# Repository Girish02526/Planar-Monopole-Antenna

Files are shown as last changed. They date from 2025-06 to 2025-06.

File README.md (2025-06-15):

# Planar Monopole Antenna Project

This repository contains all the resources related to the **Planar Monopole Antenna for Wireless and Energy Harvesting Applications**.

## 📸 Project Images

Below are the sequential images demonstrating various stages and components of the project:

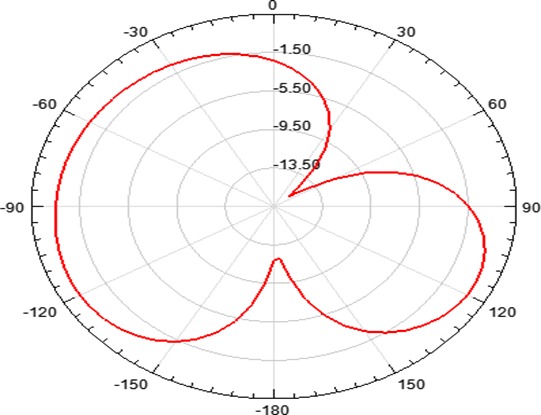
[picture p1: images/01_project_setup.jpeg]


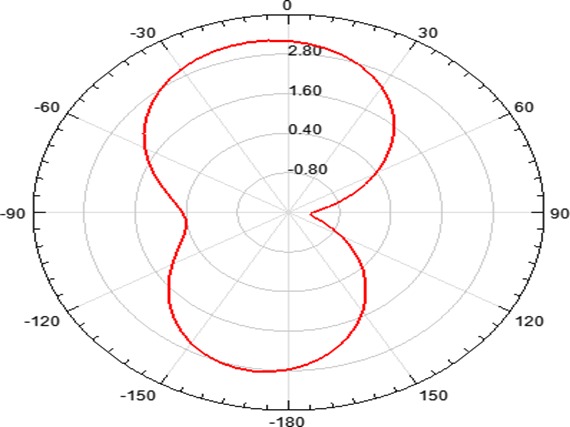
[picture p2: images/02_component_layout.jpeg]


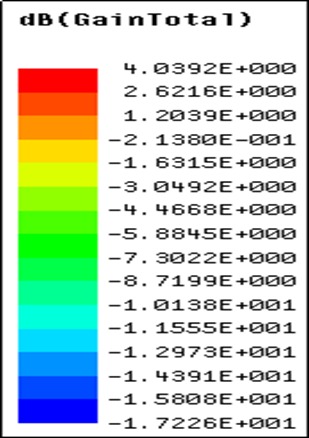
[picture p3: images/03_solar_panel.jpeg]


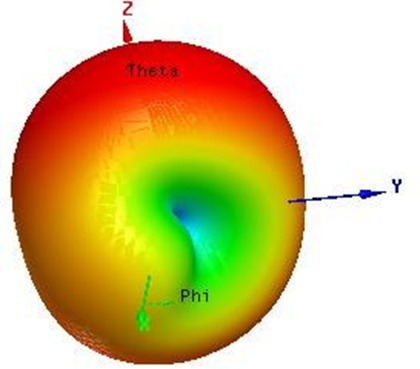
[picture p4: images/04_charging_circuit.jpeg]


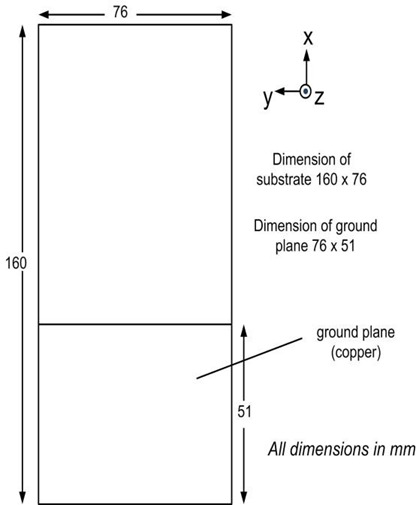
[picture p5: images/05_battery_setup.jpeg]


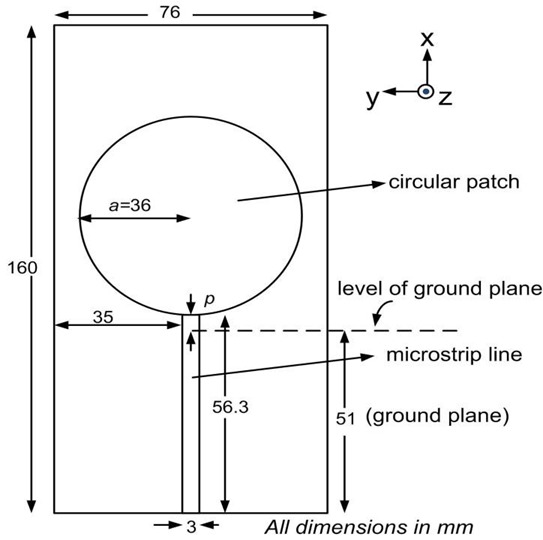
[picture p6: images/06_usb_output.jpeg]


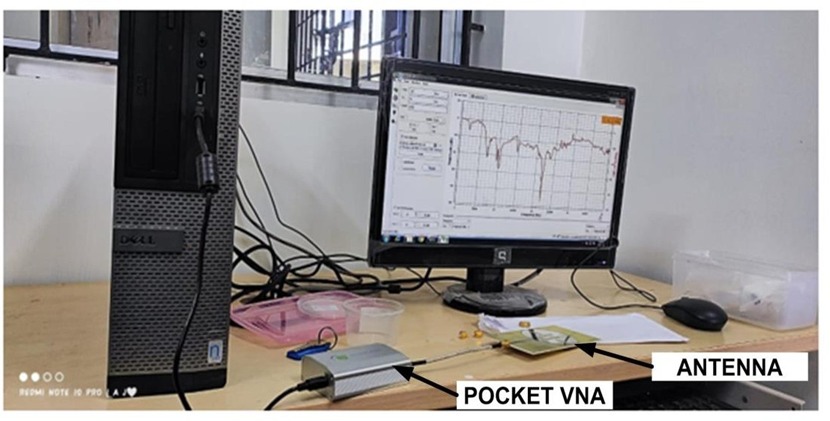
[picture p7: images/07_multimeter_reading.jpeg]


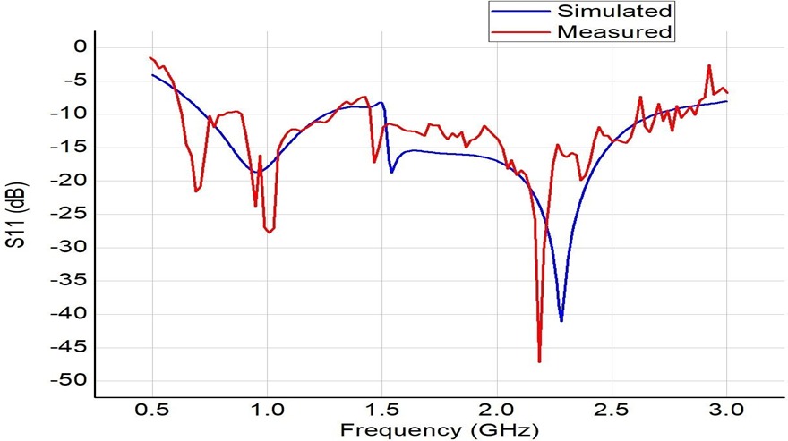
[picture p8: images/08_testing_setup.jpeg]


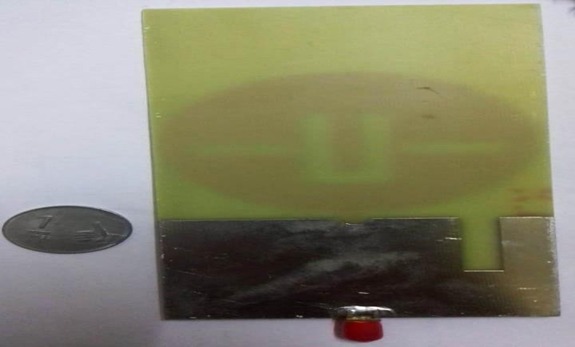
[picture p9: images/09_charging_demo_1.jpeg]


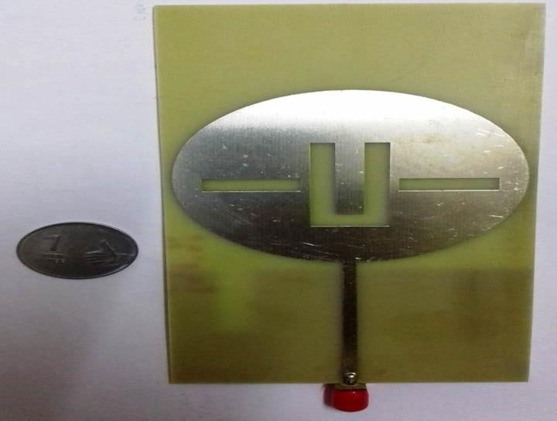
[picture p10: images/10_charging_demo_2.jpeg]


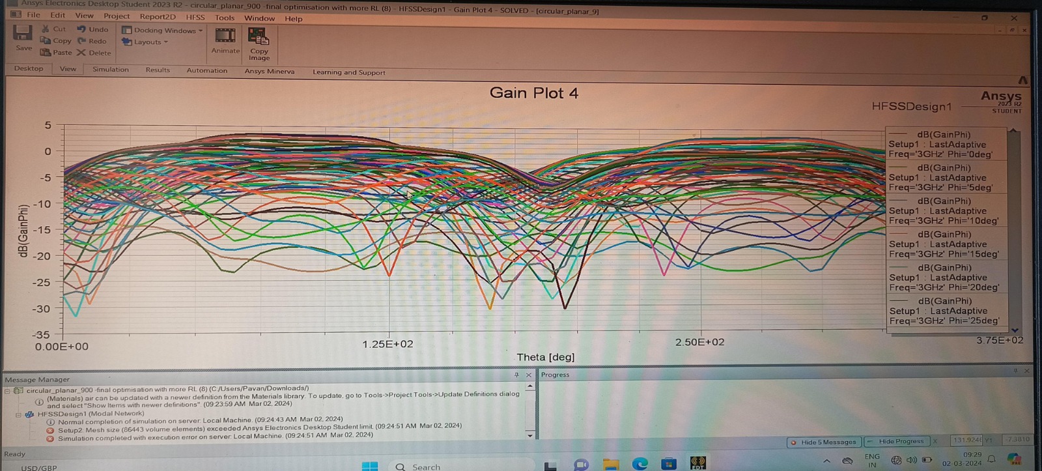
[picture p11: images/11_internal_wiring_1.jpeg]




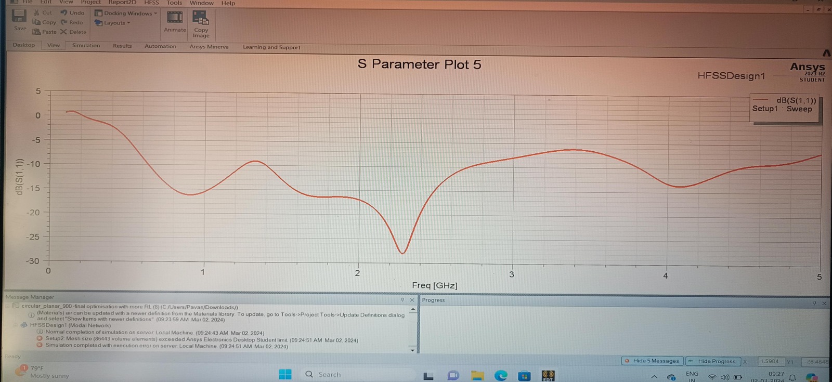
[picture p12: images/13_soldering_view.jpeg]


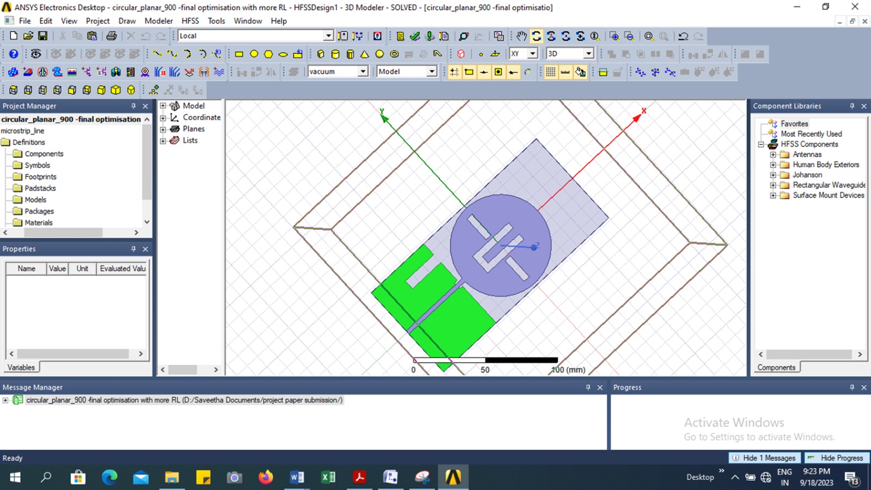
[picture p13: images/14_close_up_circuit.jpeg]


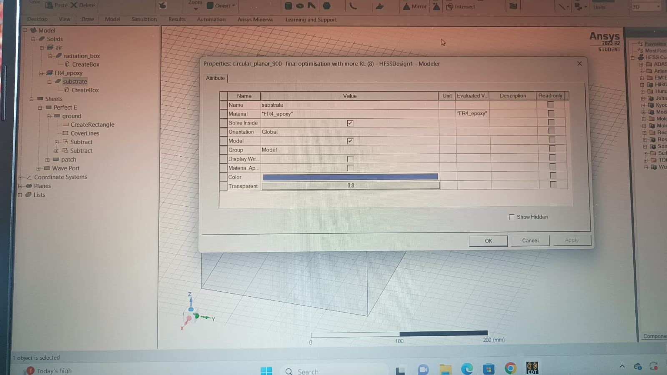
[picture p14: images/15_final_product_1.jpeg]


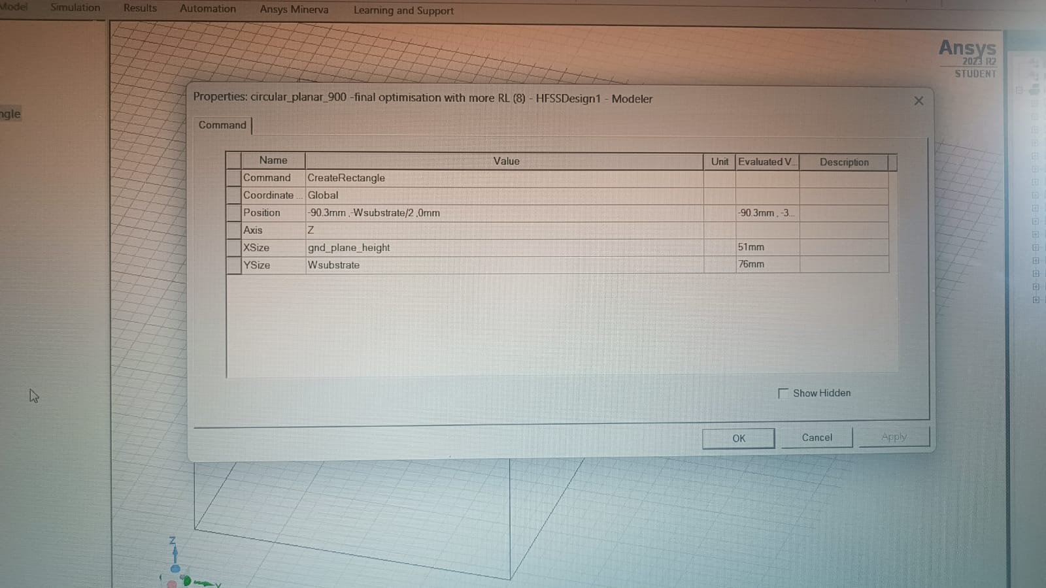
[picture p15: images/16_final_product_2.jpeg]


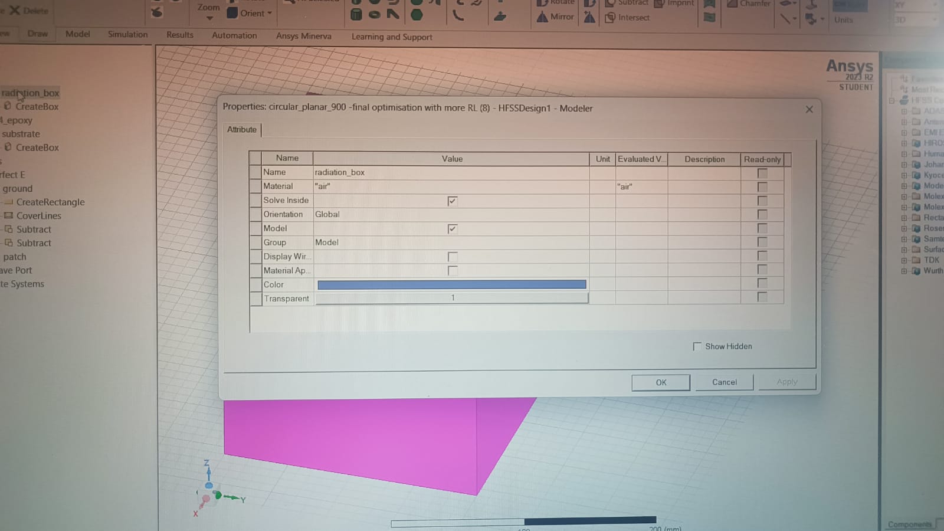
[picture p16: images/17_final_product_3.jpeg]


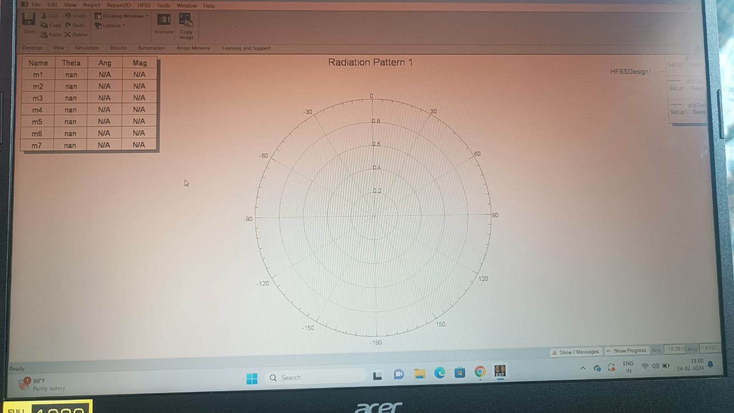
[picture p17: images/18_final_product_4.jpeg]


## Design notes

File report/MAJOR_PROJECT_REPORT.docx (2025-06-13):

## Design Of Planar Monople Antenna For Wireless and Energy Harvesting Applications

## Amit Kumar Varshney,

Dept of Electronics and Communication Engineering,

Saveetha Engineering college (Autonomous)

Chennai , TamilNadu

Chemirthipalli Girish,

Dept of Electronics and Communication Engineering,

Saveetha Engineering college (Autonomous)

Chennai , TamilNadu

girish02526@gmail.com

Duggineni Bhanu Prakash,

Dept of Electronics and Communication Engineering,

Saveetha Engineering college (Autonomous)

Chennai , TamilNadu

bhanuchowdaryduggineni@gmail.com

Abstract— A planar circular monopole antenna with slots in the patch as well as in the ground plane is presented. Slots of different shapes and sizes are etched in patch and ground plane to bring down the resonant frequency of proposed antenna and increase its bandwidth. The antenna operates over a wide frequency range, covering some of wireless standards/protocols at the same time, such as Wi-Fi, WiMAX, Bluetooth, RFID and GPS (L1). The antenna is simulated in HFSS and measured using pocket VNA. The simulated result shows S11 parameter less than -10dB from 0.72GHz to 1.24GHz and again from 1.52GHz to 2.65GHz. The measured result shows S11 parameter of around -10dB and less from 0.628GHz to 1.28GHz and again from 1.466GHz to 2.72GHz. Without using any slot in the ground plane and patch, the simulated result shows S11 parameter less than -10dB from 0.85GHz to 2.18GHz. The simulated gain obtained is around 4dBi at almost all the frequencies. Therefore simulated and measured results are in close agreement. Without using slots in the patch and ground plane, the simulated S-parameter shows S11 less than -10dB from 0.84GHz to 2.25GHz. The overall dimension of the fabricated antenna is 160mm by 76mm. The antenna is fabricated on FR4 epoxy substrate having and loss tangent 0.02. The proposed antenna, besides its use in wireless communication, finds application in energy harvesting where low frequencies are abundantly present in the environment.

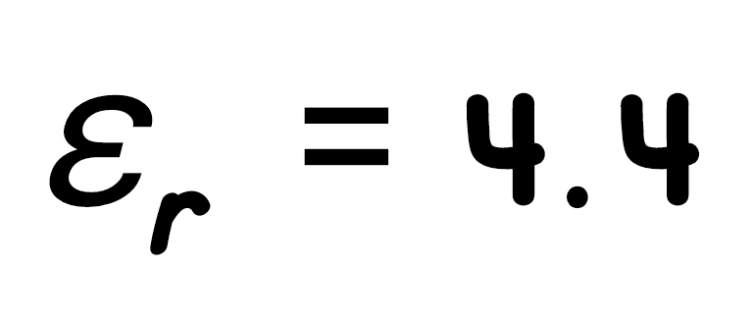
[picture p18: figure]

Keywords—circular monopole, energy harvesting, slots.

# I. Introduction

Owing to the emergence of several wireless standards and protocols it has become necessary to design an antenna that can operate in multiple frequencies. This calls for broadbanding an antenna. A planar monopole antenna is inherently broadband because it is evolved from microstrip patch antenna by increasing the substrate height and decreasing the permittivity of substrate since both height and permittivity of the substrate have direct affect on the bandwidth [1, 2]. For planar monopole antenna ground plane can be thought to be at infinity and permittivity close to 1 (air substrate) [3]. Increasing the thickness of the monopole further increases the bandwidth [3]. At the design frequency, the monopole antennas should be a quarter of a wavelength long. If the radius of the cylinder is made thicker, the bandwidth of the antennas can be increased. The same approach applies to planar monopole antennas: instead of utilizing a 50 ohm metal strip for the monopole, a wider strip (rectangular shape) or any other shape (triangular, circular, ellipse, etc.) can be used to achieve broadband characteristics. Further optimization of the broadband characteristics can be performed by introducing defects in the ground plane (by etching slots or slits) and/or etching slots/slits in the monopole. This is the guiding premise for this type of research. Different authors in the past have reported modification in the basic structure of planar microstrip and monopole antennas in order to improve the bandwidth and also to provide miniaturization. In one such paper [4], the author has reported an array of two U shaped planar monopole antennas and a slit in the ground plane to achieve 80% fractional bandwidth. Authors in [5] have designed annular ring shaped microstrip patch antenna with ground plane of hexagonal shaped to achieve 151% of fractional bandwidth due to the excitation of closely spaced multimodes [5]. The multimodes may be from same antenna or from two closely spaced antennas [6-7]. In [8], authors have reported that cutting U shaped slot in the microstrip patch/ground plane enhances bandwidth due to alteration of current path [8]. In [9] authors have reported two-element multiple-input multiple-output (MIMO) antenna for ultra wideband applications with tapered feed instead of standard feed. In this work, the two antennas are orthogonally fed which resulted in good isolation between antennas. In [10], the authors have reported three radiating strips and a back coupling pad to improve impedance matching. This structure achieves a wide bandwidth of 2.972GHz from 2.315GHz to 5.285GHz. In [11], the authors have reported U shaped microstrip patch with circular slots in the ground plane achieving 81% fractional bandwidth. In [12], the authors have reported an eye shaped slot in dipole antenna. This slot improves the gain and return loss bandwidth of antenna. The frequency of this antenna is from 3.1 to 12 GHz. The authors in [13] have reported etching complementary split ring resonator on the radiating patch of the planar monopole antenna. By this technique, a fractional bandwidth of upto 76% has been achieved.

Antennas also find applications in harnessing RF energy from environment. For better harnessing the RF energy from ambient environment, it is desired to have the antenna radiation pattern almost equal in all the directions. Monopole antennas are a very good choice for such applications. Antennas for energy harvesting applications do not require to be compact. However planar antennas are preferred as these can be integrated with microwave circuitry required with antenna for RF energy harvesting like rectifiers etc. [14] Authors in [14] have designed and optimized a rectifier combined with a broadband planar monopole antenna (called rectina) which can be used for RF energy harvesting.

The advancement of current world technology, as well as customer demand for multiple services offered by a single wireless device, has influenced the need for an antenna capable of transmitting and receiving electromagnetic waves across multiple frequency bands. A distinct frequency band is associated with each wireless service. The most prevalent wireless services are listed, along with their respective frequency ranges.

Frequency ranges wireless service

860-960MHz RFID

2.51-2.55GHz WiMAX band

2100MHz UMTS(3G of GSM)

824-890MHz CDMA

1575+-10MHz GPS

890-915MHz and 935-960MHz GSM(900)

1710-1780MHz and 1810-1880MHz GSM(1800)

1920-1980MHz and 2110-2170MHz 3G

2300-2400MHz 4G

2400-2483MHz Wi-Fi

In this paper the authors have proposed a novel broadband planar monopole antenna that will cover simultaneously a number wireless standards and protocols (especially the standards at low frequencies) so that the proposed antenna can be used in wireless as well as energy harvesting applications.

# II. Design of the proposed monopole antenna

A simple circular monopole antenna is designed and simulated in simulation software as shown in Fig. 1. One side of the substrate consists of circular monopole with microstrip line (top side) and the other side (bottom side) consists of only ground plane. The substrate used is FR4 epoxy having relative permittivity εr=4.4 and thickness h=1.6mm. The dimensions are optimized for better impedance matching. The initial length of monopole is obtained using the available analytical formulation available in literature [3]. The length of the wire monopole antenna is quarter-wave long at the design frequency with some correction factor. With increase in the thickness of the radius of the wire, the bandwidth increases. So for broadband monopole antenna the lower frequency corresponding to VSWR=2 or S11=-10dB can be calculated by equating the area of the radiating structure with the equivalent cylindrical monopole antenna having the same height as that of original antenna. Let us consider the case of a circular monopole antenna of radius ‘a’. The equivalent length of the cylindrical monopole antenna is L=2a. Now area of circle is . Area of cylinder of length L and radius r is . Equating the two areas we obtain .

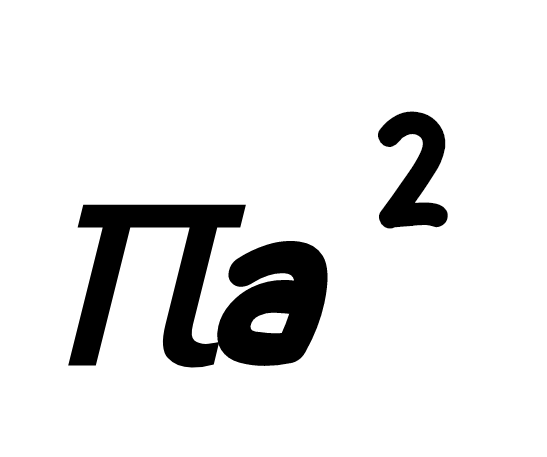
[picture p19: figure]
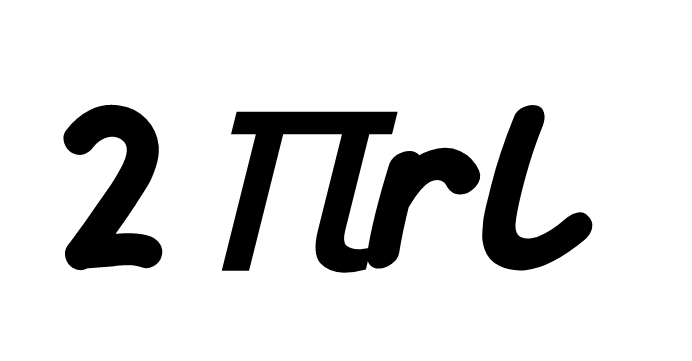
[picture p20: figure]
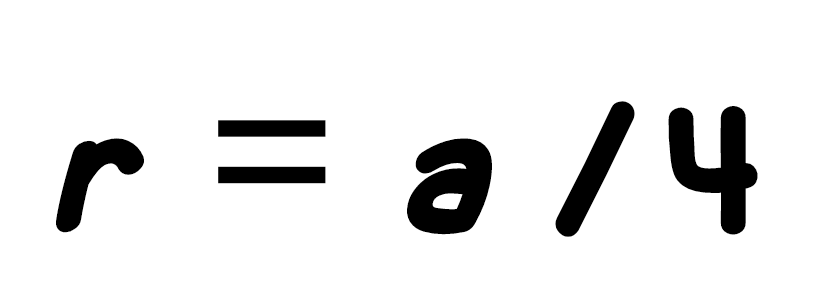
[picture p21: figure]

For a cylindrical wire monopole antenna having length L and radius r, the following relation holds [3]

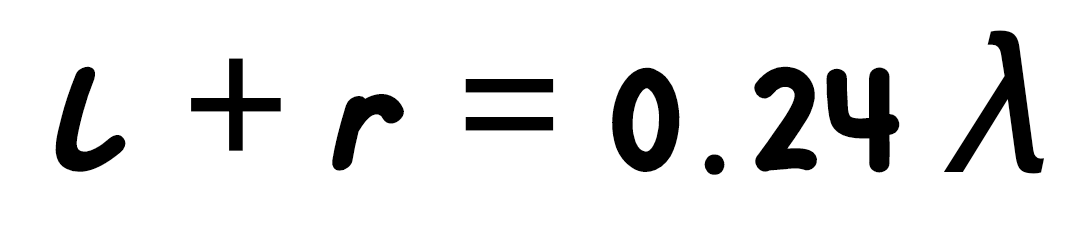
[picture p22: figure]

(1)

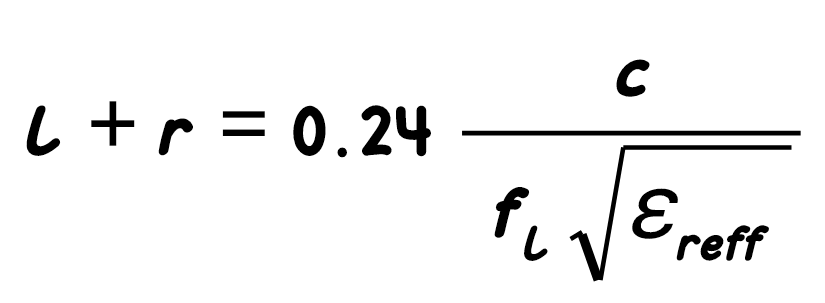
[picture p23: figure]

(2)

where is the lower cutoff frequency

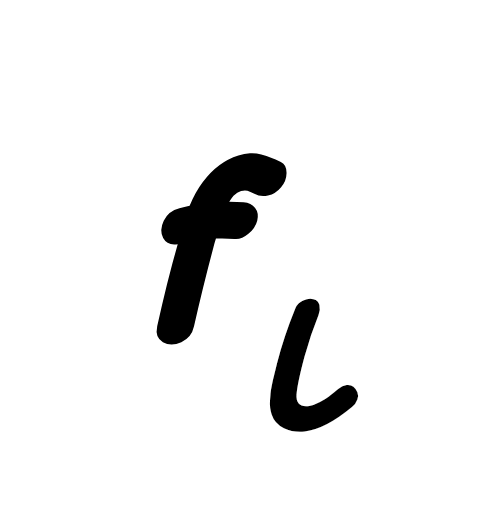
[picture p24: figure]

Here (since we are considering air dielectric)

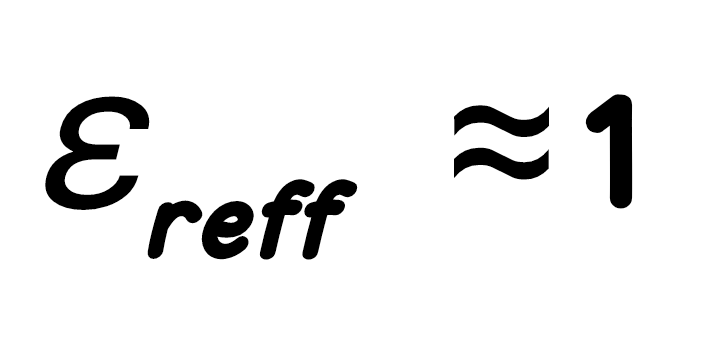
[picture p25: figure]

This simplifies to

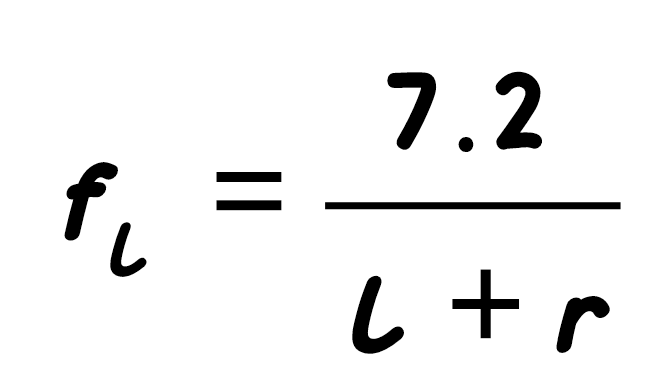
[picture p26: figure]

GHz (3)

where L and r to be considered in cm.

In order to account for the gap ‘p’ (3) modifies to

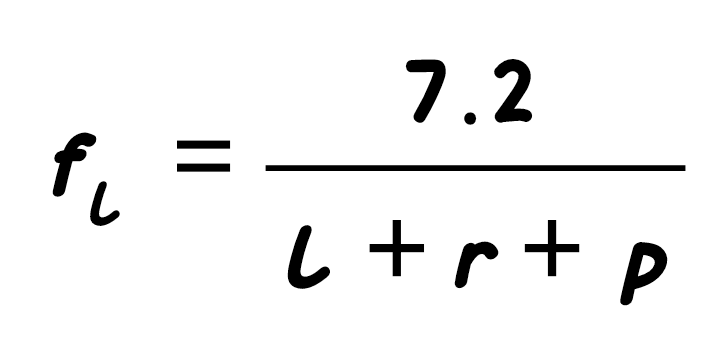
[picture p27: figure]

GHz (4)

This is the basic design equation.

In the present optimized design, a=36mm. Hence r=9mm, L=72mm, p=5.3mm. Putting these values in (4) we obtain fL=834.298MHz.

(a)

(b)

Fig. 1 Top side (a) and bottom side (b) of simple circular monopole antenna on FR4 epoxy substrate having thickness 1.6mm and relative permittivity 4.4

After optimization of the basic circular monopole antenna, three slots in the patch are introduced, one U shaped and two rectangular shaped on either side of U shaped, and two slots in the ground plane, one slot of semicircular shape just below the transmission line and another rectangular slot at a distance away from the transmission line. The dimensions of the slots in the patch and in the ground plane are optimized in the simulation software for better impedance matching. The final optimized dimensions of the antenna with all the slots is shown in Fig. 2

(a)

(b)Fig. 2 Top side (a) and bottom side (b) of slotted circular monopole antenna on FR4 epoxy substrate having thickness 1.6mm and relative permittivity 4.4

# III. Results And Discussion

The simulated S11 parameter (magnitude only) less than -10dB for the simple circular shaped monopole antenna is obtained from 0.85GHz to 2.18GHz as shown in Fig. 3. After cutting slots in the patch and ground plane, the S11 parameter less than -10dB is obtained from 0.72GHz to 1.24GHz and again from 1.52GHz to 2.65GHz as shown in the same Fig. 3 We thus observe that after cutting slots, the lower cutoff frequency is reduced and the upper cutoff frequency is increased, S11 parameter is slightly more than -10dB around 1.3GHz. The simulated 3D radiation pattern (plot of gain in dBi) of the slotted monopole antenna at 0.9GHz is shown in Fig.4. The E-plane and H-plane radiation pattern of the proposed antenna is shown in Fig. 5. The proposed antenna is then fabricated and its S-parameter measured using pocket VNA. The fabricated antenna is shown in Fig. 6 and the pocket VNA with the antenna connected is shown in Fig. 7. The measured S-parameter shows S11 less than -10dB from 0.628GHz to 1.28GHz and again from 1.466GHz to 2.72GHz. The measured and simulated S-parameter S11 are compared in Fig. 8. The results show good agreement between measured and simulated S-parameter S11.

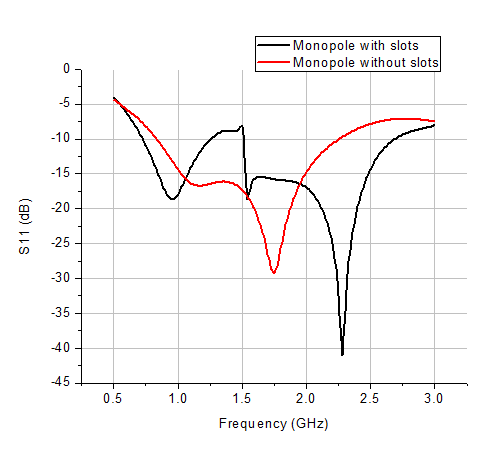
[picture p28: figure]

Fig. 3. Simulated S11 parameter (magnitude only) of simple circular monopole antenna with and without slots.

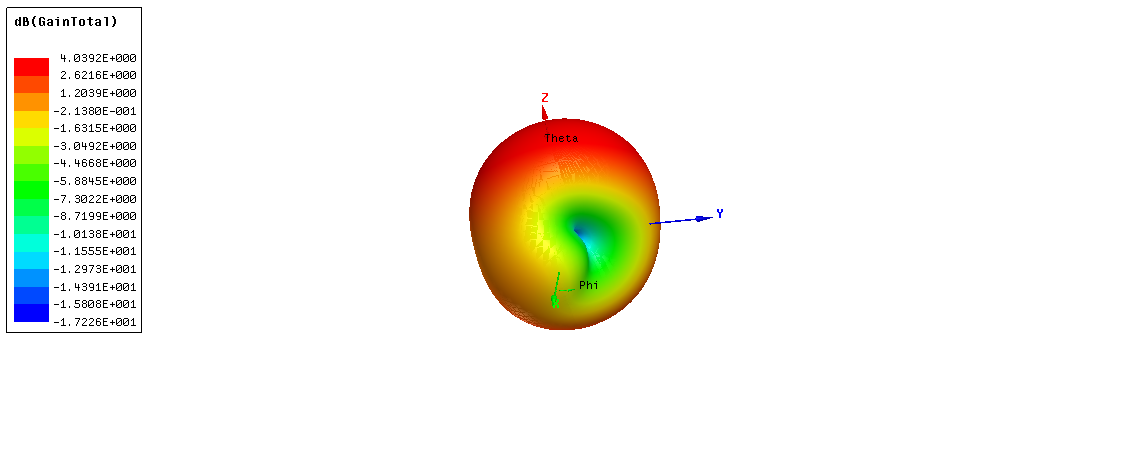
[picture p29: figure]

Fig. 4. Simulated 3D radiation pattern of slotted monopole antenna at 0.9GHz

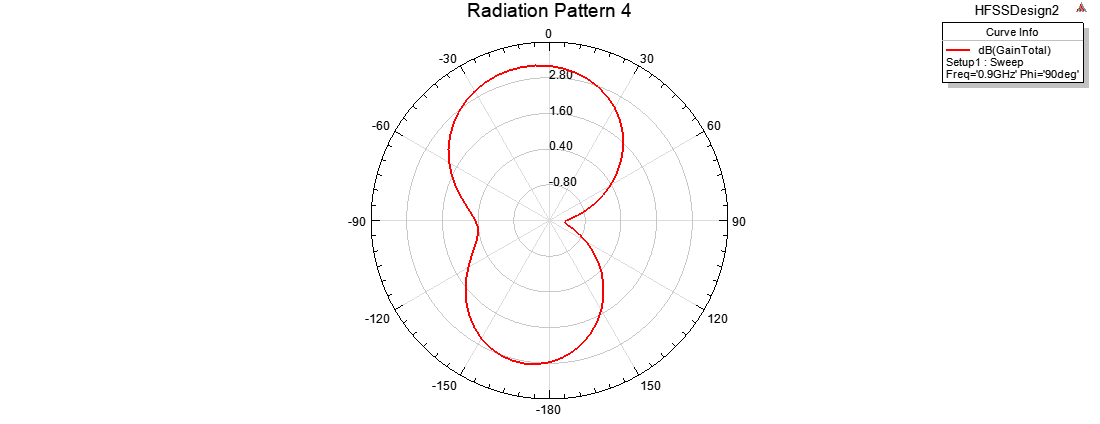
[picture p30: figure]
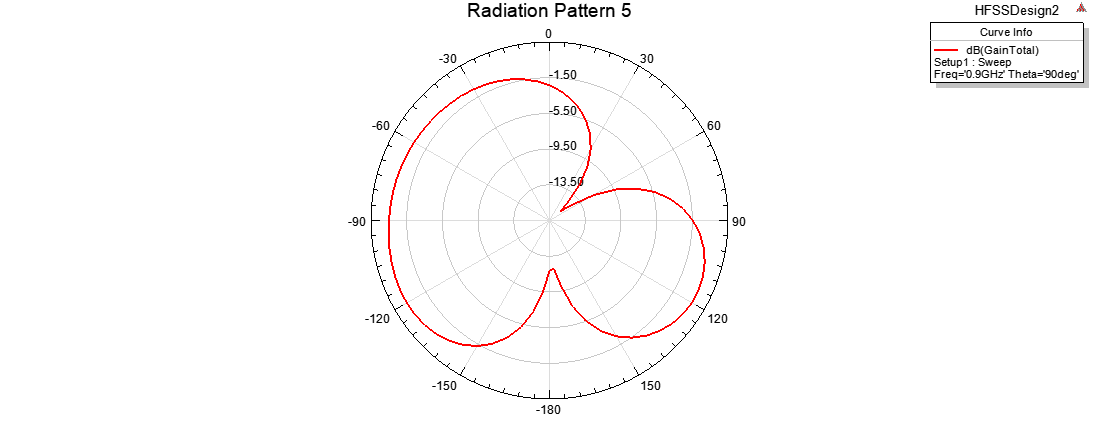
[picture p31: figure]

(a) (b) (b)

Fig. 5. Simulated 2D radiation pattern in y-z plane () (H-plane) (a) and in x-y plane () (b) at 0.9GHz (E-plane)

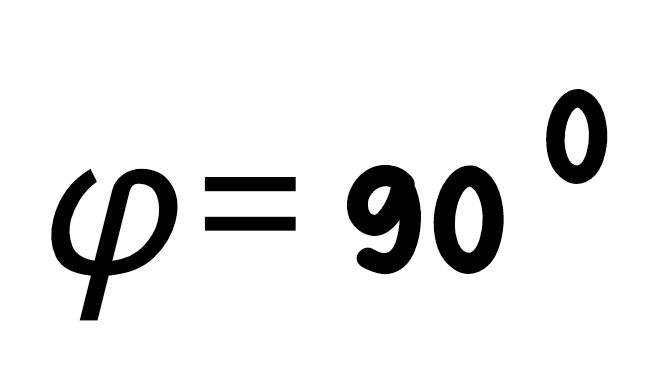
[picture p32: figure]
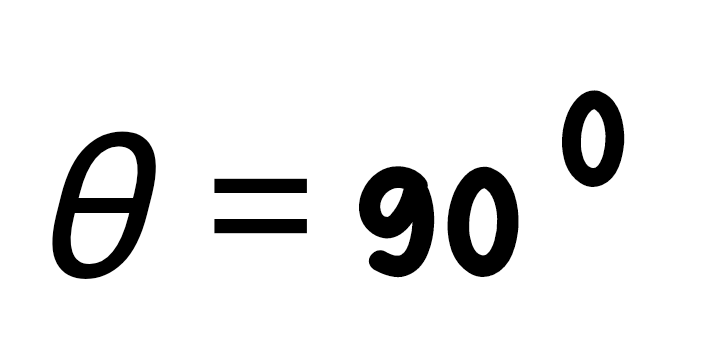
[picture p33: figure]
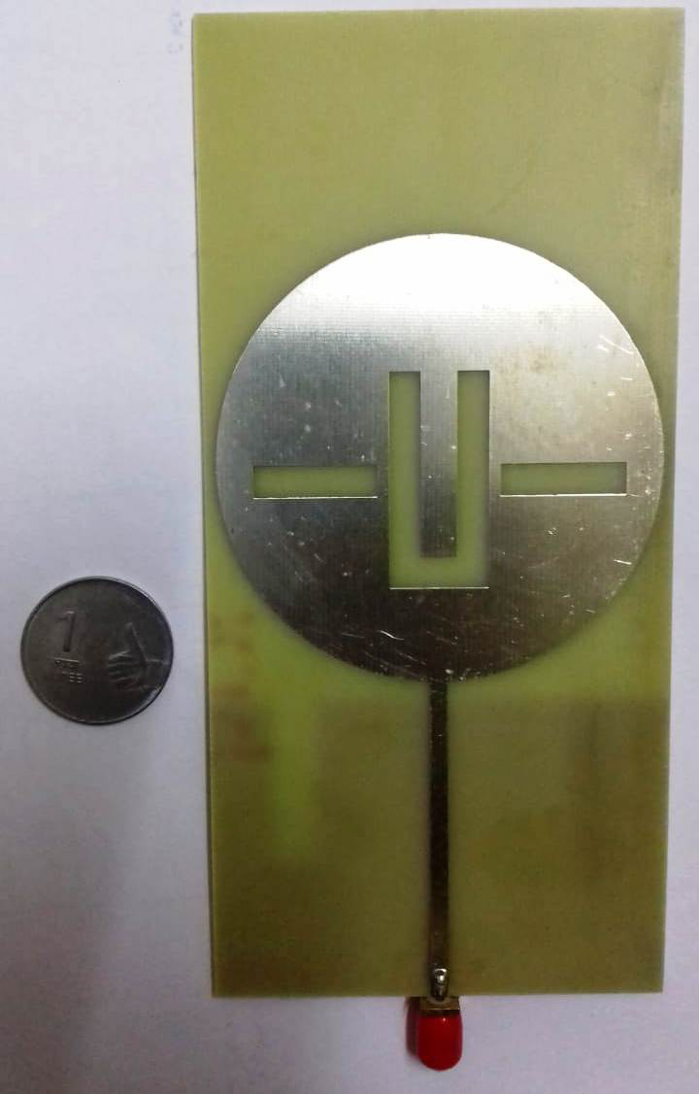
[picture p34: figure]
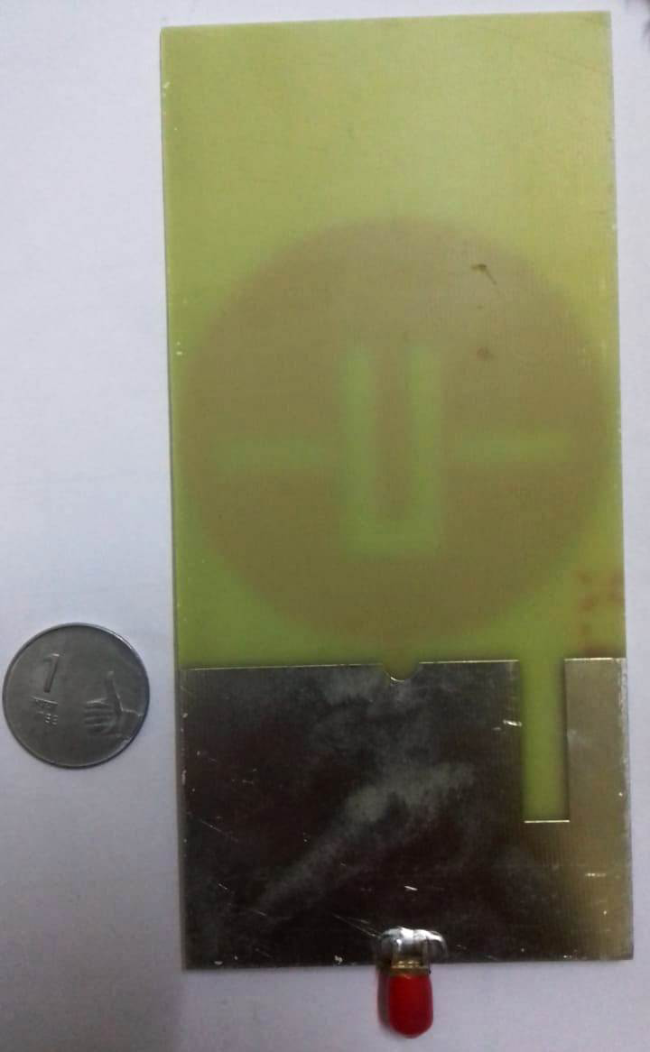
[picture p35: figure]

(a) (b)

Fig. 6. Top side view (a) and bottom side view (b) of fabricated slotted monopole antenna

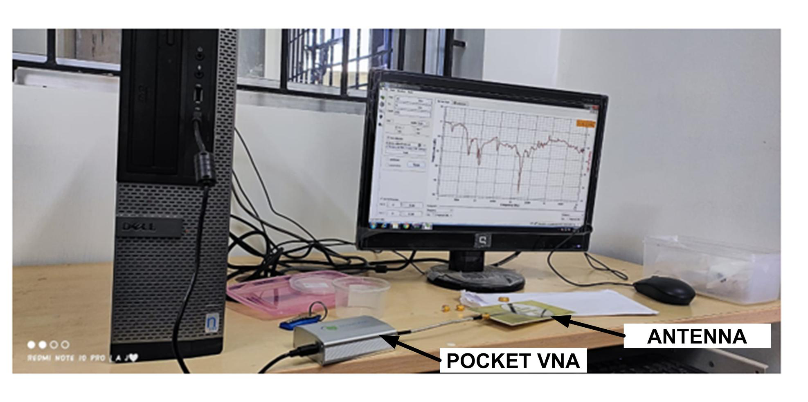
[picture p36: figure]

Fig. 7. Experimental set for the measurement of S11 parameter of the proposed antenna using pocket VNA.

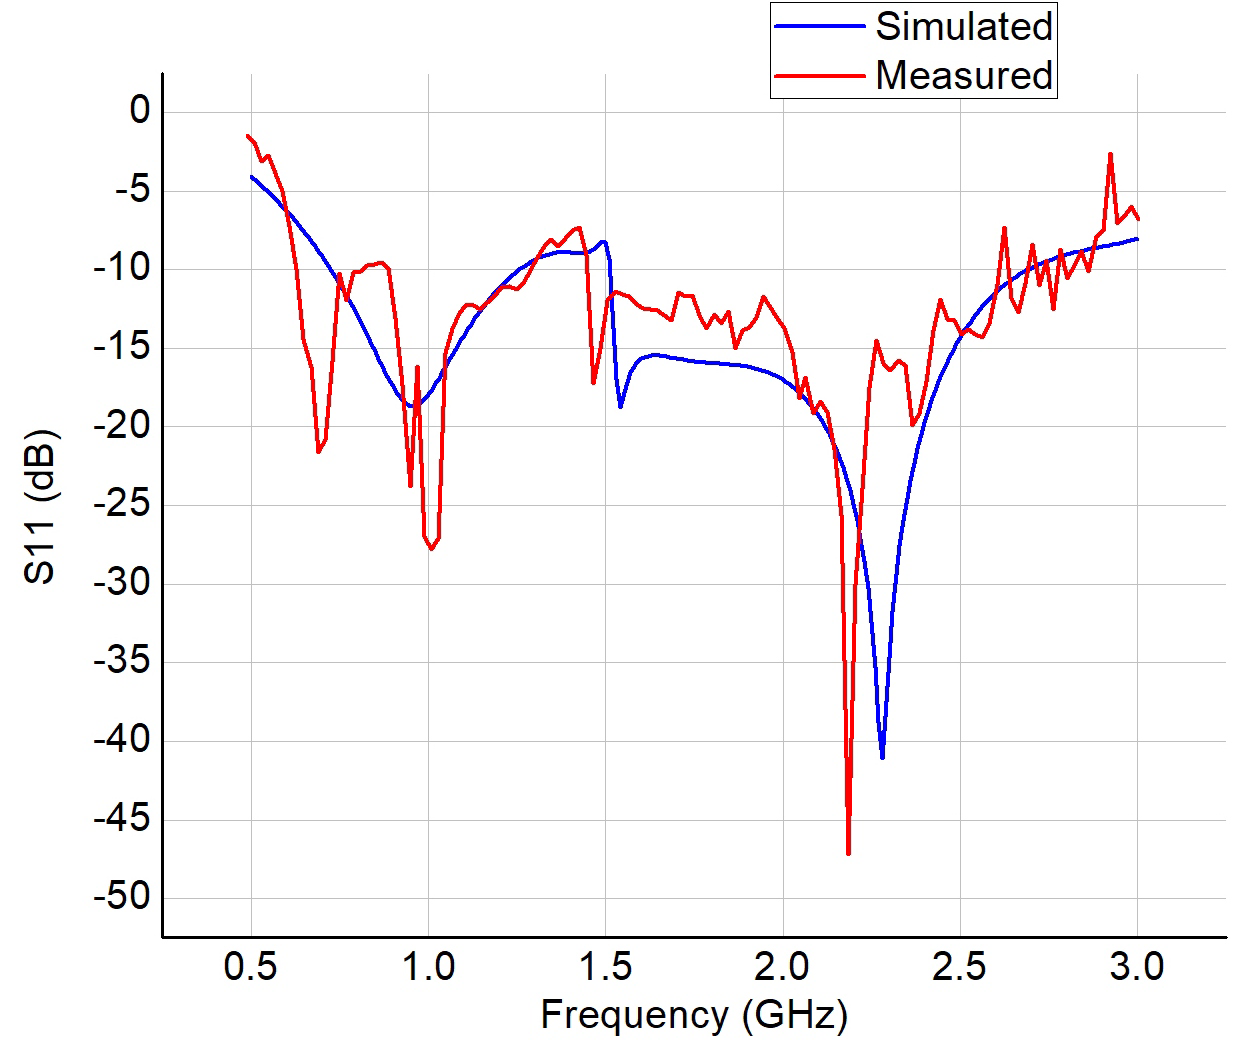
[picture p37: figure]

Fig. 8. Measured and simulated S11 parameter for the proposed slotted monopole antenna

# IV. Conclusion

A simple circular monopole antenna provides high bandwidth. The lower cutoff frequency of the monopole antenna can be lowered by cutting lots in the radiating patch and/or ground plane, however doing such also introduces some band of frequencies where the S11 parameter deteriorates. The proposed antenna finds application in wireless standards like Wifi, WiMAX, Bluetooth, RFID, GPS etc. and also finds application in energy harvesting.

V. ACKNOWLEDGEMENT

The authors are grateful to the management of Saveetha Engineering College for providing the necessary lab facilities and full support for carrying out this work

REFRENCES

[1] John D Kraus, Ronald J Marhefka and Ahmad S Khan, Antennas and Wave Propagation, Fifth Edition, McGraw Hill Education Pvt. Ltd., 2018.

[2] C. A. Balanis, Antenna Theory Analysis and Design, pp.728-730, John Wiley & Sons, 2nd Edition.

[3] Girish Kumar and K P Ray, Broadband Microstrip Antennas, Artech House Boston • London, pp. 361.

[4] S.De, S.Sarkar, S.Biswas, D.Sarkar and P.P.Sarkar “Investigation on broadband microstrip two element monopole antenna with high gain” IETE Journal of Research, Vol.59, Issue.4, Pp.400-403,2013.

[5] S. De and P.P. Sarkar “A High Gain Ultra-wideband Monopole Antenna” International Journal of Electronics and Communications (AEÜ). Vol.69, Pp.1113-1117, 2015.

[6] S.De, S.Sarkar, S.Biswas, D.Sarkar and P.P.Sarkar “Investigation on broadband microstrip two element monopole antenna with high gain” IETE Journal of Research, Vol.59, Issue.4, Pp.400-403,2013.

[7] S. De and P.P. Sarkar “A High Gain Ultra-wideband Monopole Antenna” International Journal of Electronics and Communications (AEÜ). Vol.69, Pp.1113-1117, 2015.

[8] K. Mandal, A. K. Saw, M. K. Das and PP Sarkar, “Bandwidth enhancement for microstrip patch antenna using symmetric inverted U slot,” International Journal of Electronics and Communication Technology, vol. 3, pp. 64-66, 2012.

[9] Pratyaksh, B. Ananda Venkatesan, K. Kalimuthu, RanvijayTanwar and Harjot Kaur. “Design of Ultrawide Band Planar Monopole Antenna for MIMO Applications.” (2019).

[10] Ming-An Chung and Chih-Wei Yang, “A Miniaturized Planar Monopole Antenna Based on a Coupling Structure for Compact Mobile Internet of Things (IoT) and Electric Vehicles (EVs) Device Applications in 5G, LTE, WLAN, WiMAX, Sirius/XM Radio, V2X, and DSRC Wireless Systems,” International Journal of Antennas and Propagation, vol. 2021, pp. 1-12, 2021

[11] K. Mandal and P.P. Sarkar, “High gain wide-band U-shaped patch antennas with modified ground planes,” IEEE Trans. Antennas Propagation, vol. 61, pp. 2279-2282, April-2013.

[12] A R Rajini , Ebenezer Abishek, S Ramesh, and V Rajendran, “Compact Printed Planar Eye Shaped Dipole Antenna for Ultra-Wibeband Wireless Applications.” Journal of Applied Science and Engineering (Taiwan), vol. 25, issue 5, pp. 761-766, 2021.

[13] Isaac B. T. da Silva, Humberto D. de Andrade, José L. da Silva, Humberto C. C. Fernandes and T. Wakabayashi, “Influence of Complementary Split Ring Resonator Dimensions in Ultra Wideband Microstrip Patch Antenna,” 9th European Conference on Antennas and Propagation (EuCAP), 2015.

[14] Saranya N, Kesavamurthy T. Design and performance analysis of broadband rectenna for an efficient RF energy harvesting application. Int J RF Microw Comput Aided Eng. 2019.

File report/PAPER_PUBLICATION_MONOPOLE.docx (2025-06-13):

## Design Of Planar Monople Antenna For Wireless and Energy Harvesting Application

Amit Kumar Varshney

Dept of Electronics and Communication Engineering,

Saveetha Engineering college (Autonomous)

Chennai , TamilNadu

Chemirthipalli Girish,(212220060034)

Student, Dept of Electronics and Communication Engineering,

Saveetha Engineering college (Autonomous)

Chennai , TamilNadu

girish02526@gmail.com

Duggineni Bhanu Prakash,( 212220060042)

Student, Dept of Electronics and Communication Engineering,

Saveetha Engineering college (Autonomous)

Chennai , TamilNadu

bhanuchowdaryduggineni@gmail.com

Abstract— A planar circular monopole antenna with slots in the patch as well as in the ground plane is presented. Slots of different shapes and sizes are etched in patch and ground plane to bring down the resonant frequency of proposed antenna and increase its bandwidth. The antenna operates over a wide frequency range, covering some of wireless standards/protocols at the same time, such as Wi-Fi, WiMAX, Bluetooth, RFID and GPS (L1). The antenna is simulated in HFSS and measured using pocket VNA. The simulated result shows S11 parameter less than -10dB from 0.72GHz to 1.24GHz and again from 1.52GHz to 2.65GHz. The measured result shows S11 parameter of around -10dB and less from 0.628GHz to 1.28GHz and again from 1.466GHz to 2.72GHz. Without using any slot in the ground plane and patch, the simulated result shows S11 parameter less than -10dB from 0.85GHz to 2.18GHz. The simulated gain obtained is around 4dBi at almost all the frequencies. Therefore simulated and measured results are in close agreement. Without using slots in the patch and ground plane, the simulated S-parameter shows S11 less than -10dB from 0.84GHz to 2.25GHz. The overall dimension of the fabricated antenna is 160mm by 76mm. The antenna is fabricated on FR4 epoxy substrate having and loss tangent 0.02. The proposed antenna, besides its use in wireless communication, finds application in energy harvesting where low frequencies are abundantly present in the environment.

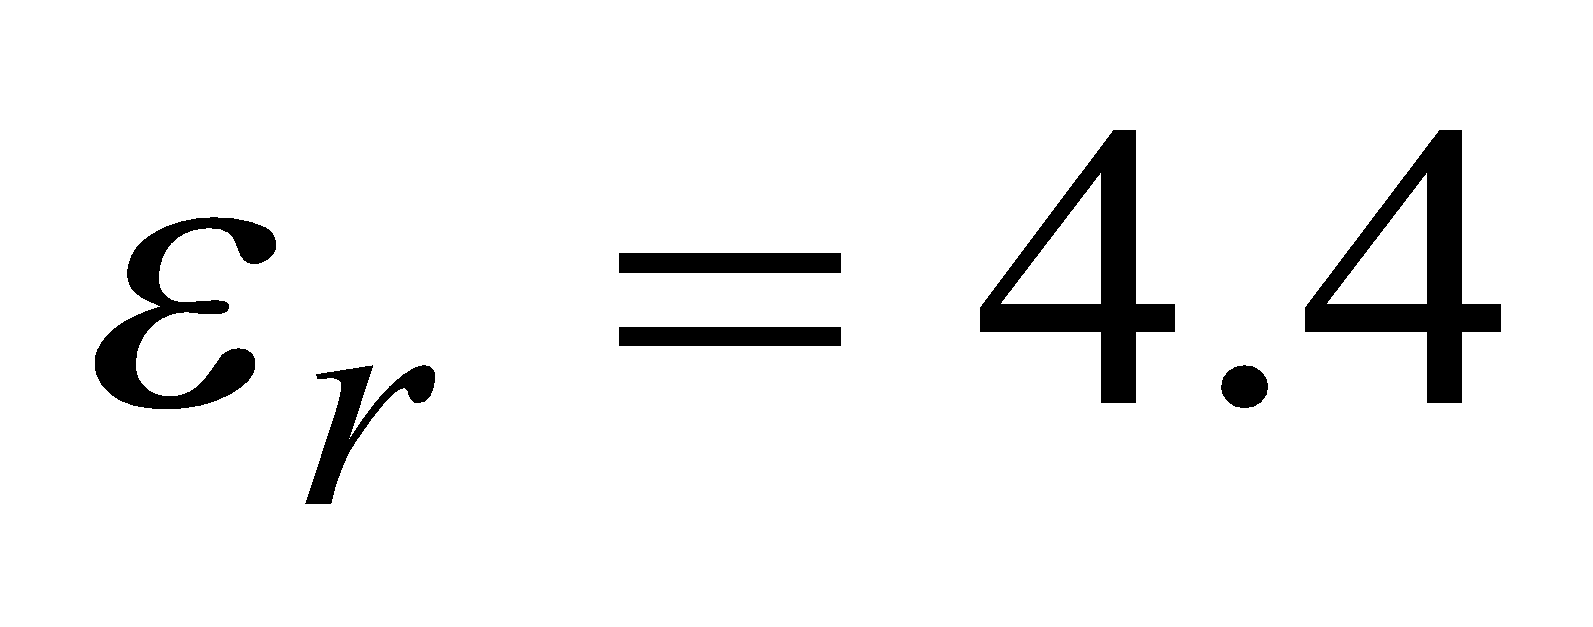
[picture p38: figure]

Keywords—circular monopole, energy harvesting, slots.

# I. Introduction

Owing to the emergence of several wireless standards and protocols it has become necessary to design an antenna that can operate in multiple frequencies. This calls for broadbanding an antenna. A planar monopole antenna is inherently broadband because it is evolved from microstrip patch antenna by increasing the substrate height and decreasing the permittivity of substrate since both height and permittivity of the substrate have direct affect on the bandwidth [1, 2]. For planar monopole antenna ground plane can be thought to be at infinity and permittivity close to 1 (air substrate) [3]. Increasing the thickness of the monopole further increases the bandwidth [3]. At the design frequency, the monopole antennas should be a quarter of a wavelength long. If the radius of the cylinder is made thicker, the bandwidth of the antennas can be increased. The same approach applies to planar monopole antennas: instead of utilizing a 50 ohm metal strip for the monopole, a wider strip (rectangular shape) or any other shape (triangular, circular, ellipse, etc.) can be used to achieve broadband characteristics. Further optimization of the broadband characteristics can be performed by introducing defects in the ground plane (by etching slots or slits) and/or etching slots/slits in the monopole. This is the guiding premise for this type of research. Different authors in the past have reported modification in the basic structure of planar microstrip and monopole antennas in order to improve the bandwidth and also to provide miniaturization. In one such paper [4], the author has reported an array of two U shaped planar monopole antennas and a slit in the ground plane to achieve 80% fractional bandwidth. Authors in [5] have designed annular ring shaped microstrip patch antenna with ground plane of hexagonal shaped to achieve 151% of fractional bandwidth due to the excitation of closely spaced multimodes [5]. The multimodes may be from same antenna or from two closely spaced antennas [6-7]. In [8], authors have reported that cutting U shaped slot in the microstrip patch/ground plane enhances bandwidth due to alteration of current path [8]. In [9] authors have reported two-element multiple-input multiple-output (MIMO) antenna for ultra wideband applications with tapered feed instead of standard feed. In this work, the two antennas are orthogonally fed which resulted in good isolation between antennas. In [10], the authors have reported three radiating strips and a back coupling pad to improve impedance matching. This structure achieves a wide bandwidth of 2.972GHz from 2.315GHz to 5.285GHz. In [11], the authors have reported U shaped microstrip patch with circular slots in the ground plane achieving 81% fractional bandwidth. In [12], the authors have reported an eye shaped slot in dipole antenna. This slot improves the gain and return loss bandwidth of antenna. The frequency of this antenna is from 3.1 to 12 GHz. The authors in [13] have reported etching complementary split ring resonator on the radiating patch of the planar monopole antenna. By this technique, a fractional bandwidth of upto 76% has been achieved.

Antennas also find applications in harnessing RF energy from environment. For better harnessing the RF energy from ambient environment, it is desired to have the antenna radiation pattern almost equal in all the directions. Monopole antennas are a very good choice for such applications. Antennas for energy harvesting applications do not require to be compact. However planar antennas are preferred as these can be integrated with microwave circuitry required with antenna for RF energy harvesting like rectifiers etc. [14] Authors in [14] have designed and optimized a rectifier combined with a broadband planar monopole antenna (called rectina) which can be used for RF energy harvesting.

The advancement of current world technology, as well as customer demand for multiple services offered by a single wireless device, has influenced the need for an antenna capable of transmitting and receiving electromagnetic waves across multiple frequency bands. A distinct frequency band is associated with each wireless service. The most prevalent wireless services are listed, along with their respective frequency ranges.

Frequency ranges wireless service

860-960MHz RFID

2.51-2.55GHz WiMAX band

2100MHz UMTS(3G of GSM)

824-890MHz CDMA

1575+-10MHz GPS

890-915MHz and 935-960MHz GSM(900)

1710-1780MHz and 1810-1880MHz GSM(1800)

1920-1980MHz and 2110-2170MHz 3G

2300-2400MHz 4G

2400-2483MHz Wi-Fi

In this paper the authors have proposed a novel broadband planar monopole antenna that will cover simultaneously a number wireless standards and protocols (especially the standards at low frequencies) so that the proposed antenna can be used in wireless as well as energy harvesting applications.

# II. Design of the proposed monopole antenna

A simple circular monopole antenna is designed and simulated in simulation software as shown in Fig. 1. One side of the substrate consists of circular monopole with microstrip line (top side) and the other side (bottom side) consists of only ground plane. The substrate used is FR4 epoxy having relative permittivity εr=4.4 and thickness h=1.6mm. The dimensions are optimized for better impedance matching. The initial length of monopole is obtained using the available analytical formulation available in literature [3]. The length of the wire monopole antenna is quarter-wave long at the design frequency with some correction factor. With increase in the thickness of the radius of the wire, the bandwidth increases. So for broadband monopole antenna the lower frequency corresponding to VSWR=2 or S11=-10dB can be calculated by equating the area of the radiating structure with the equivalent cylindrical monopole antenna having the same height as that of original antenna. Let us consider the case of a circular monopole antenna of radius ‘a’. The equivalent length of the cylindrical monopole antenna is L=2a. Now area of circle is . Area of cylinder of length L and radius r is . Equating the two areas we obtain .

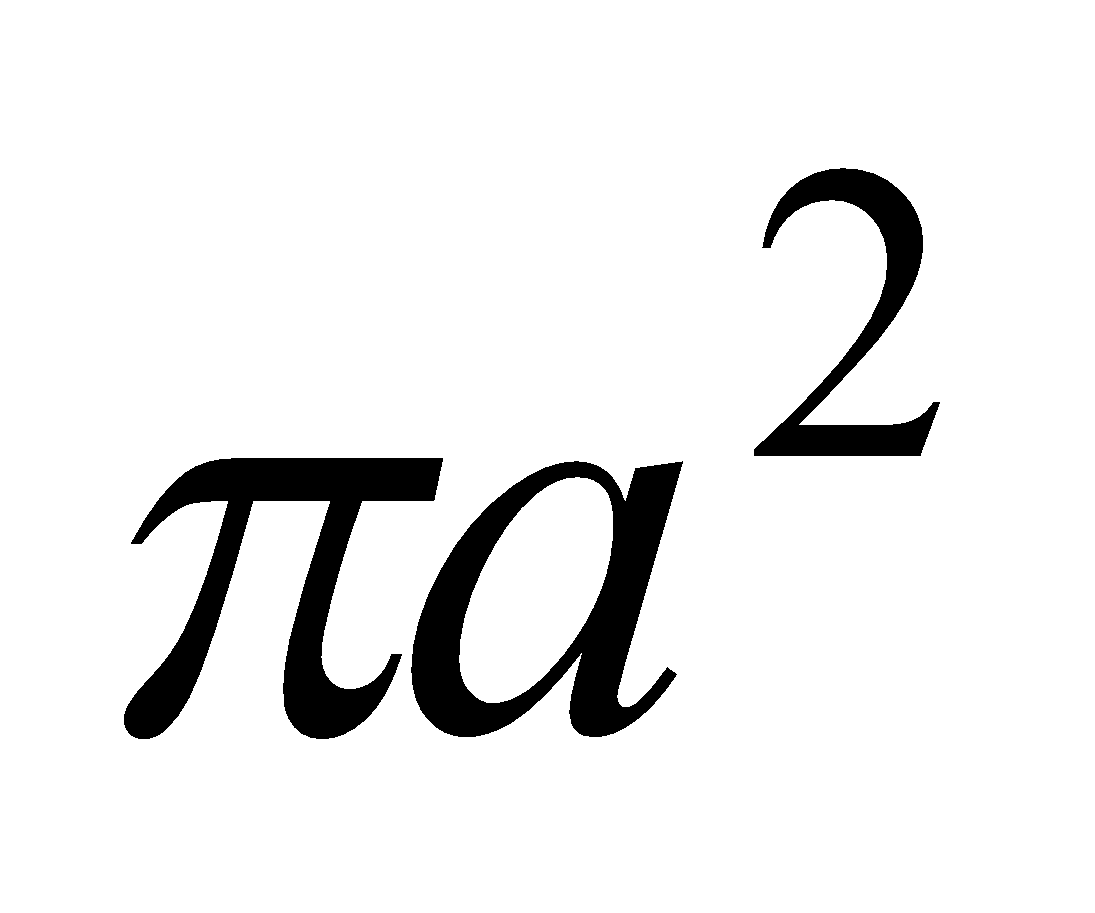
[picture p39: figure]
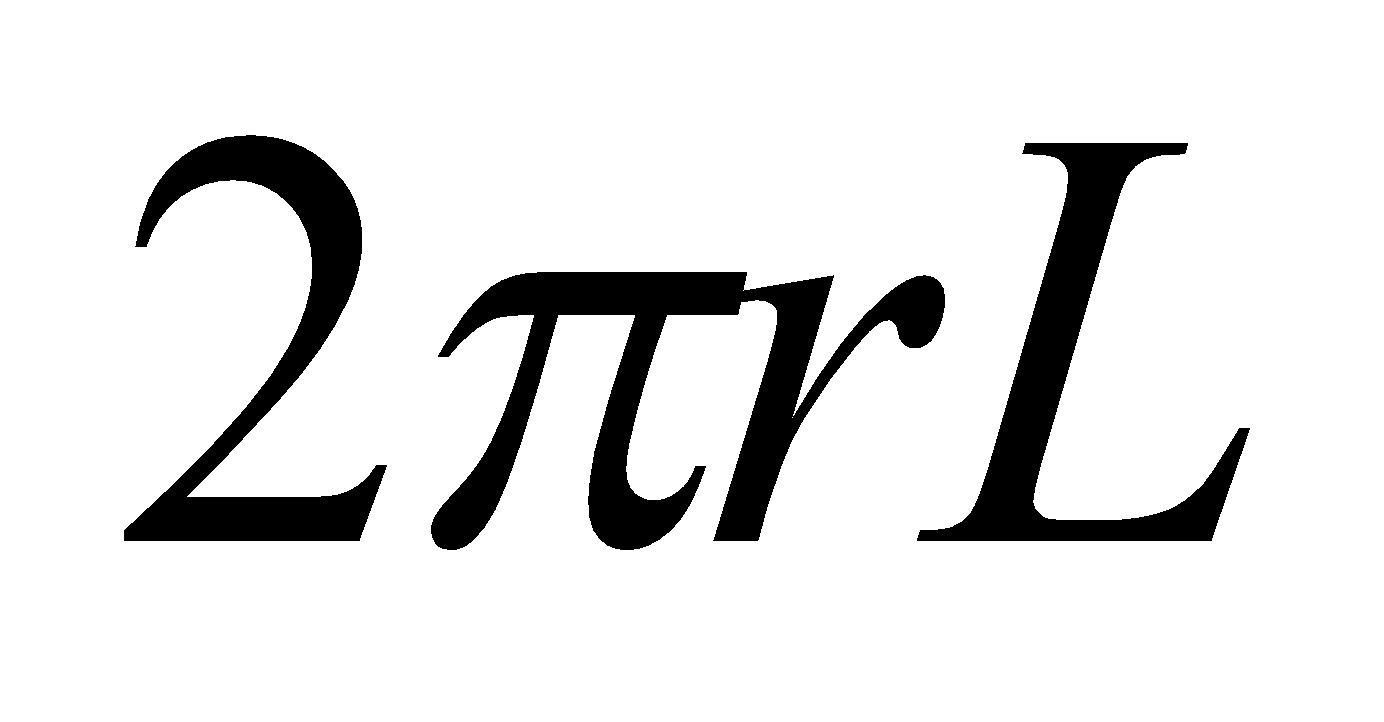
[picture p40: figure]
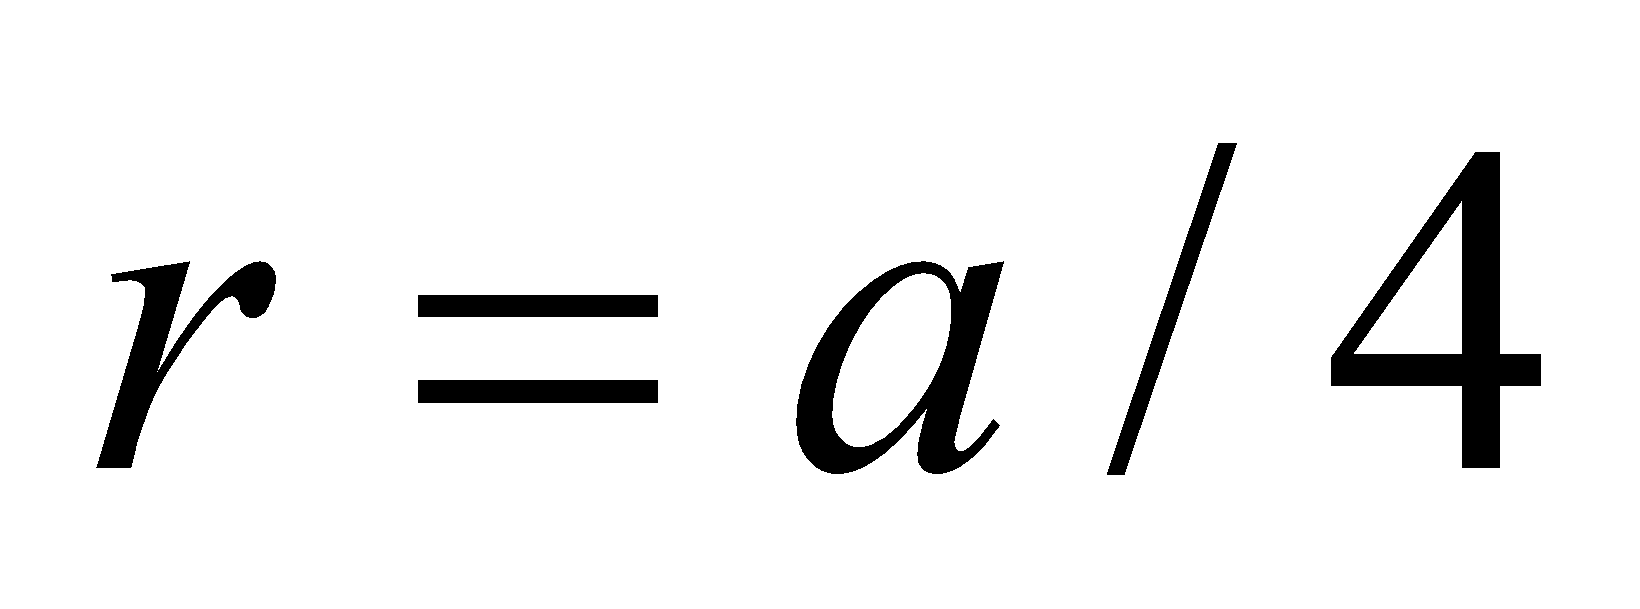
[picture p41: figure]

For a cylindrical wire monopole antenna having length L and radius r, the following relation holds [3]


(1)


(2)

where is the lower cutoff frequency


Here (since we are considering air dielectric)


This simplifies to


GHz (3)

where L and r to be considered in cm.

In order to account for the gap ‘p’ (3) modifies to


GHz (4)

This is the basic design equation.

In the present optimized design, a=36mm. Hence r=9mm, L=72mm, p=5.3mm. Putting these values in (4) we obtain fL=834.298MHz.

(a)

(b)

Fig. 1 Top side (a) and bottom side (b) of simple circular monopole antenna on FR4 epoxy substrate having thickness 1.6mm and relative permittivity 4.4

After optimization of the basic circular monopole antenna, three slots in the patch are introduced, one U shaped and two rectangular shaped on either side of U shaped, and two slots in the ground plane, one slot of semicircular shape just below the transmission line and another rectangular slot at a distance away from the transmission line. The dimensions of the slots in the patch and in the ground plane are optimized in the simulation software for better impedance matching. The final optimized dimensions of the antenna with all the slots is shown in Fig. 2

(a)

(b)Fig. 2 Top side (a) and bottom side (b) of slotted circular monopole antenna on FR4 epoxy substrate having thickness 1.6mm and relative permittivity 4.4

# III. Results And Discussion

The simulated S11 parameter (magnitude only) less than -10dB for the simple circular shaped monopole antenna is obtained from 0.85GHz to 2.18GHz as shown in Fig. 3. After cutting slots in the patch and ground plane, the S11 parameter less than -10dB is obtained from 0.72GHz to 1.24GHz and again from 1.52GHz to 2.65GHz as shown in the same Fig. 3 We thus observe that after cutting slots, the lower cutoff frequency is reduced and the upper cutoff frequency is increased, S11 parameter is slightly more than -10dB around 1.3GHz. The simulated 3D radiation pattern (plot of gain in dBi) of the slotted monopole antenna at 0.9GHz is shown in Fig.4. The E-plane and H-plane radiation pattern of the proposed antenna is shown in Fig. 5. The proposed antenna is then fabricated and its S-parameter measured using pocket VNA. The fabricated antenna is shown in Fig. 6 and the pocket VNA with the antenna connected is shown in Fig. 7. The measured S-parameter shows S11 less than -10dB from 0.628GHz to 1.28GHz and again from 1.466GHz to 2.72GHz. The measured and simulated S-parameter S11 are compared in Fig. 8. The results show good agreement between measured and simulated S-parameter S11.


Fig. 3. Simulated S11 parameter (magnitude only) of simple circular monopole antenna with and without slots.


Fig. 4. Simulated 3D radiation pattern of slotted monopole antenna at 0.9GHz


(a) (b) (b)

Fig. 5. Simulated 2D radiation pattern in y-z plane () (H-plane) (a) and in x-y plane () (b) at 0.9GHz (E-plane)


(a) (b)

Fig. 6. Top side view (a) and bottom side view (b) of fabricated slotted monopole antenna


Fig. 7. Experimental set for the measurement of S11 parameter of the proposed antenna using pocket VNA.


Fig. 8. Measured and simulated S11 parameter for the proposed slotted monopole antenna

# IV. Conclusion

A simple circular monopole antenna provides high bandwidth. The lower cutoff frequency of the monopole antenna can be lowered by cutting lots in the radiating patch and/or ground plane, however doing such also introduces some band of frequencies where the S11 parameter deteriorates. The proposed antenna finds application in wireless standards like Wifi, WiMAX, Bluetooth, RFID, GPS etc. and also finds application in energy harvesting.

V. ACKNOWLEDGEMENT

The authors are grateful to the management of Saveetha Engineering College for providing the necessary lab facilities and full support for carrying out this work

REFRENCES

[1] John D Kraus, Ronald J Marhefka and Ahmad S Khan, Antennas and Wave Propagation, Fifth Edition, McGraw Hill Education Pvt. Ltd., 2018.

[2] C. A. Balanis, Antenna Theory Analysis and Design, pp.728-730, John Wiley & Sons, 2nd Edition.

[3] Girish Kumar and K P Ray, Broadband Microstrip Antennas, Artech House Boston • London, pp. 361.

[4] S.De, S.Sarkar, S.Biswas, D.Sarkar and P.P.Sarkar “Investigation on broadband microstrip two element monopole antenna with high gain” IETE Journal of Research, Vol.59, Issue.4, Pp.400-403,2013.

[5] S. De and P.P. Sarkar “A High Gain Ultra-wideband Monopole Antenna” International Journal of Electronics and Communications (AEÜ). Vol.69, Pp.1113-1117, 2015.

[6] S.De, S.Sarkar, S.Biswas, D.Sarkar and P.P.Sarkar “Investigation on broadband microstrip two element monopole antenna with high gain” IETE Journal of Research, Vol.59, Issue.4, Pp.400-403,2013.

[7] S. De and P.P. Sarkar “A High Gain Ultra-wideband Monopole Antenna” International Journal of Electronics and Communications (AEÜ). Vol.69, Pp.1113-1117, 2015.

[8] K. Mandal, A. K. Saw, M. K. Das and PP Sarkar, “Bandwidth enhancement for microstrip patch antenna using symmetric inverted U slot,” International Journal of Electronics and Communication Technology, vol. 3, pp. 64-66, 2012.

[9] Pratyaksh, B. Ananda Venkatesan, K. Kalimuthu, RanvijayTanwar and Harjot Kaur. “Design of Ultrawide Band Planar Monopole Antenna for MIMO Applications.” (2019).

[10] Ming-An Chung and Chih-Wei Yang, “A Miniaturized Planar Monopole Antenna Based on a Coupling Structure for Compact Mobile Internet of Things (IoT) and Electric Vehicles (EVs) Device Applications in 5G, LTE, WLAN, WiMAX, Sirius/XM Radio, V2X, and DSRC Wireless Systems,” International Journal of Antennas and Propagation, vol. 2021, pp. 1-12, 2021

[11] K. Mandal and P.P. Sarkar, “High gain wide-band U-shaped patch antennas with modified ground planes,” IEEE Trans. Antennas Propagation, vol. 61, pp. 2279-2282, April-2013.

[12] A R Rajini , Ebenezer Abishek, S Ramesh, and V Rajendran, “Compact Printed Planar Eye Shaped Dipole Antenna for Ultra-Wibeband Wireless Applications.” Journal of Applied Science and Engineering (Taiwan), vol. 25, issue 5, pp. 761-766, 2021.

[13] Isaac B. T. da Silva, Humberto D. de Andrade, José L. da Silva, Humberto C. C. Fernandes and T. Wakabayashi, “Influence of Complementary Split Ring Resonator Dimensions in Ultra Wideband Microstrip Patch Antenna,” 9th European Conference on Antennas and Propagation (EuCAP), 2015.

[14] Saranya N, Kesavamurthy T. Design and performance analysis of broadband rectenna for an efficient RF energy harvesting application. Int J RF Microw Comput Aided Eng. 2019.

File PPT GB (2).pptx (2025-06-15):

## Design Of Planar Monople Antenna For Wireless and Energy Harvesting Applications


UNDER THE GUIDENCE OF
Dr.AMIT KUMAR VARSHNEY,
Associate Professor,
Department of
ELECTRONICS AND
COMMUNICATION ENGINEERING

TEAM MEMBERS:
DUGGINENI BHANU PRAKASH 212220060042
CHEMIRTHIPALLI GIRISH 212220060034

## ABSTRACT

- A planar circular monopole antenna with slots in the patch as well as in the ground plane is presented. Slots of different shapes and sizes are etched in patch and ground plane to bring down the resonant frequency of proposed antenna and increase its bandwidth
- This paper presents the design, simulation, and optimization of a broadband planar antenna tailored for wireless applications requiring point-to-point communication.
- The proposed broadband planar antenna design offers a versatile solution for wireless applications requiring point-to-point communication. Through careful optimization and simulation-driven design, the antenna achieves remarkable bandwidth, gain, and radiation properties.
- This work contributes to the advancement of wireless communication systems by providing a reliable and efficient antenna option for establishing robust connections between distant points. Further experimental validation and integration into practical communication setups are recommended for a comprehensive assessment of the antenna's performance in real-world scenarios.

## INTRODUCTION

- Owing to the emergence of several wireless standards and protocols it has become necessary to design an antenna that can operate in multiple frequencies. This calls for broad banding an antenna.
- A planar monopole antenna is inherently broadband because it is evolved from microstrip patch antenna by increasing the substrate height and decreasing the permittivity of substrate since both height and permittivity of the substrate have direct affect on the bandwidth.
- For planar monopole antenna ground plane can be thought to be at infinity and permittivity close to 1 (air substrate)
- Increasing the thickness of the monopole further increases the bandwidth. At the design frequency, the monopole antennas should be a quarter of a wavelength long. If the radius of the cylinder is made thicker, the bandwidth of the antennas can be increased.
- The advancement of current world technology, as well as customer demand for multiple services offered by a single wireless device, has influenced the need for an antenna capable of transmitting and receiving electromagnetic waves across multiple frequency bands.
- In this paper the authors have proposed a novel broadband planar monopole antenna that will cover simultaneously a number wireless standards and protocols (especially the standards at low frequencies) so that the proposed antenna can be used in wireless as well as energy harvesting applications.

## PROBLEM STATEMENT

- To design planar fat monopole antenna and optimize the length and breadth of monopole and the ground plane so as to increase its bandwidth. There may be slots and/slits in monopole as well as ground plane so as to reject some specific frequencies

## LITERATURE REVIEW

Title of Paper | Algorithm Used | Advantages / Disadvantages
"Design of Compact Dual-Band Antenna for IoT and RFID" | Genetic Algorithm (GA) | Advantages: Dual-band operation, suitable for IoT and RFID applications. Disadvantages: Limited frequency agility.
"A Compact Planar Monopole Antenna for IoT Applications" | Particle Swarm Optimization (PSO) | Advantages: Compact size, impedance matching, suitable for IoT. Disadvantages: Single-band operation.
"Wideband Planar Monopole Antenna for 5G Communication" | Finite-Element Method (FEM) | Advantages: Wideband operation for 5G, good gain. Disadvantages: Complex geometry, limited multiband capability.
"A Miniaturized Multiband Antenna for Energy Harvesting" | Genetic Algorithm (GA) | Advantages: Multiband operation, energy harvesting capability. Disadvantages: Smaller bandwidth, reduced gain.
"Design of a Dual-Band Monopole Antenna for Wi-Fi and WiMAX" | Particle Swarm Optimization (PSO) | Advantages: Dual-band operation, suitable for Wi-Fi and WiMAX. Disadvantages: Limited bandwidth.
"Planar Monopole Antenna for Energy Harvesting in RF Bands" | Analytical Design | Advantages: Optimized for energy harvesting, simple design. Disadvantages: May lack communication efficiency.

## EXISTING SYSTEM

- There were various existing methods and techniques for designing broadband planar antennas for wireless applications, particularly for point-to-point communication. Some of these methods include:
- Microstrip patch antennas are commonly used for designing broadband planar antennas due to their compact size and ease of integration. Various feeding techniques, such as inset-fed, microstrip line-fed, and aperture-coupled feeding, have been employed to achieve wide bandwidth.
- Proximity Coupled Feed This technique involves placing a feed element close to the radiating patch, allowing for improved bandwidth and impedance matching. It's often used to enhance the antenna's bandwidth and performance.
- Antennas involve coupling the radiating element to a microstrip line through an aperture. This technique helps in achieving wider bandwidth and better impedance matching.
- HFSS can be integrated into the antenna design to enhance its performance and achieve broadband characteristics. These surfaces can be used to control radiation patterns and impedance across a wide frequency range.

## PROPOSED SYSTEM

- A simple circular monopole antenna is designed and simulated in simulation software . One side of the substrate consists of circular monopole with microstrip line (top side) and the other side (bottom side) consists of only ground plane.
- The substrate used is FR4 epoxy having relative permittivity εr=4.4 and thickness h=1.6mm. The dimensions are optimized for better impedance matching. The initial length of monopole is obtained using the available analytical formulation available in literature
- The length of the wire monopole antenna is quarter-wave long at the design frequency with some correction factor. With increase in the thickness of the radius of the wire, the bandwidth increases. So for broadband monopole antenna the lower frequency corresponding to VSWR=2 or S11=-10dB can be calculated by equating the area of the radiating structure with the equivalent cylindrical monopole antenna having the same height as that of original antenna.

## PROPOSED SYSTEM – BLOCK DIAGRAM

Simulation of simple planar monopole antenna at 2.4GHZ(narrow band)

Simulation and optimization of fat circular planar monopole antenna with centre frequency at 2.4GHZ(Broadband)

Cutting Slots/Slits in the ground plane and patch for introduction of notch in the frequency response and bandwidth enhancement at lower frequency

After optimization of size and shapes of slots in simulation software the designed antenna is fabricated

Fabricated antenna parameters measured using pocket VNA

## PROPOSED SYSTEM – BLOCK DIAGRAM


## RESULTS:


## RESULTS:


## RESULTS :


## CONCLUSION

- A simple circular monopole antenna provides high bandwidth.
- The lower cutoff frequency of the monopole antenna can be lowered by cutting lots in the radiating patch and/or ground plane, however doing such also introduces some band of frequencies where the S11 parameter deteriorates.
- The proposed antenna finds application in wireless standards like Wifi, WiMAX, Bluetooth, RFID, GPS etc. and also finds application in energy harvesting.

## REFERENCES

- John D Kraus, Ronald J Marhefka and Ahmad S Khan, Antennas and Wave Propagation, Fifth Edition, McGraw Hill Education Pvt. Ltd., 2018.
- C. A. Balanis, Antenna Theory Analysis and Design, pp.728-730, John Wiley & Sons, 2nd Edition.
- Girish Kumar and K P Ray, Broadband Microstrip Antennas, Artech House Boston • London, pp. 361.
- S.De, S.Sarkar, S.Biswas, D.Sarkar and P.P.Sarkar “Investigation on broadband microstrip two element monopole antenna with high gain” IETE Journal of Research, Vol.59, Issue.4, Pp.400-403,2013.
- S. De and P.P. Sarkar “A High Gain Ultra-wideband Monopole Antenna” International Journal of Electronics and Communications (AEÜ). Vol.69, Pp.1113-1117, 2015.
- S.De, S.Sarkar, S.Biswas, D.Sarkar and P.P.Sarkar “Investigation on broadband microstrip two element monopole antenna with high gain” IETE Journal of Research, Vol.59, Issue.4, Pp.400-403,2013.
- S. De and P.P. Sarkar “A High Gain Ultra-wideband Monopole Antenna” International Journal of Electronics and Communications (AEÜ). Vol.69, Pp.1113-1117, 2015.

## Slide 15

THANK YOU

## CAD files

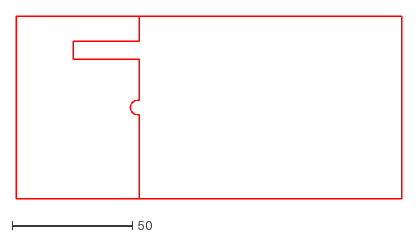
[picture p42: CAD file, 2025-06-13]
simulation/monopole_ground.dxf
160.0 x 76.0

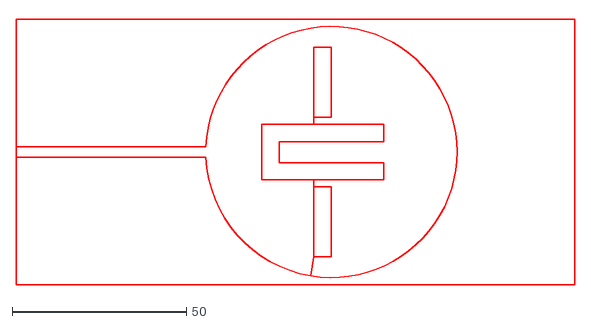
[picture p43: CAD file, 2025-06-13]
simulation/monopole_patch.dxf
160.0 x 76.9
